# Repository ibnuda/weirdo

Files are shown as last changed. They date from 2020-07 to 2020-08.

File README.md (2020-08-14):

# Weirdo

It's a split keyboard that uses 1 Promicro (or its clone) and RJ45.

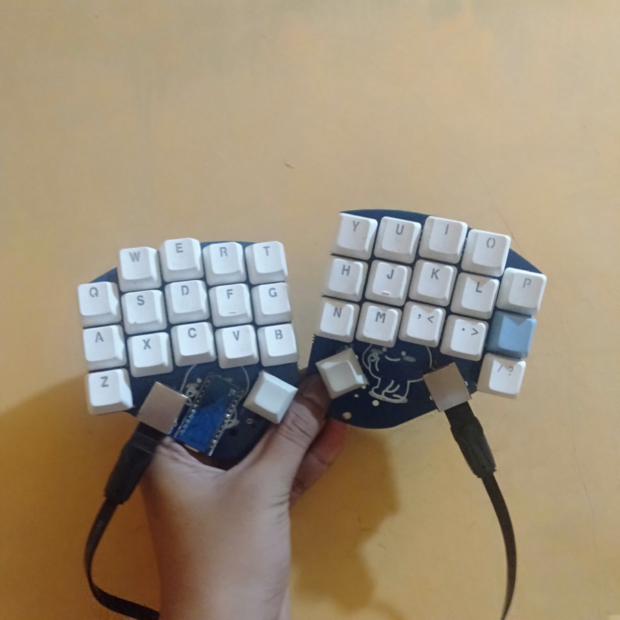
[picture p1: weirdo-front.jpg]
Front


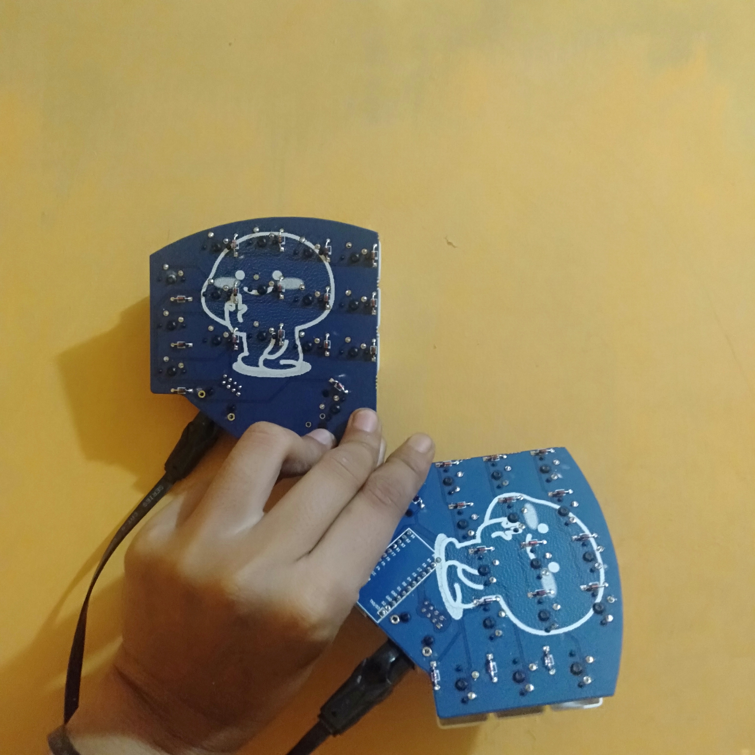
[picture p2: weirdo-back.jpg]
Back


## Why?

Just because

## Does It Work?

Of course it works.

## Firmware?

It uses [QMK](https://qmk.fm) as the firmware.

## Keymaps?

Default: [default](https://github.com/ibnuda/qmk_firmware/tree/weirdo/keyboards/weirdo/keymaps/default)

[Denny Tom's Chording Engine](https://github.com/qmk/qmk_firmware/tree/master/users/dennytom/chording_engine):
[rick's combo](https://github.com/ibnuda/qmk_firmware/tree/weirdo/keyboards/weirdo/keymaps/rick-combo)

## License

GPLv3

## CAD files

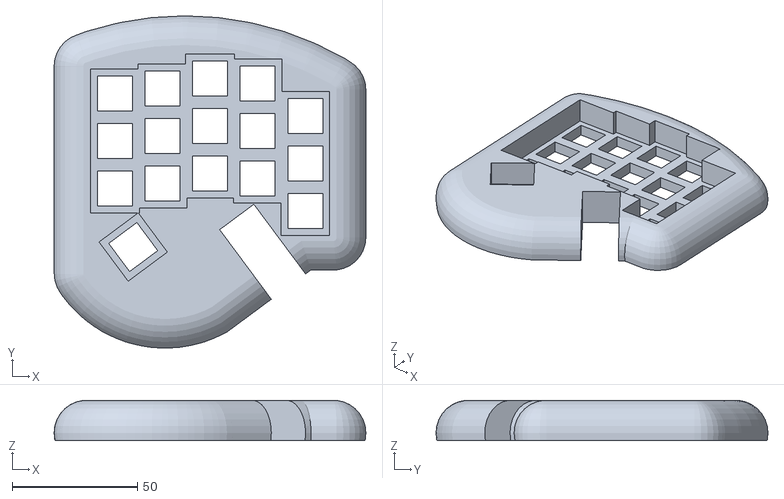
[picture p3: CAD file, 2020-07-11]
top-right-case.stl
124.5 x 132.5 x 16.0

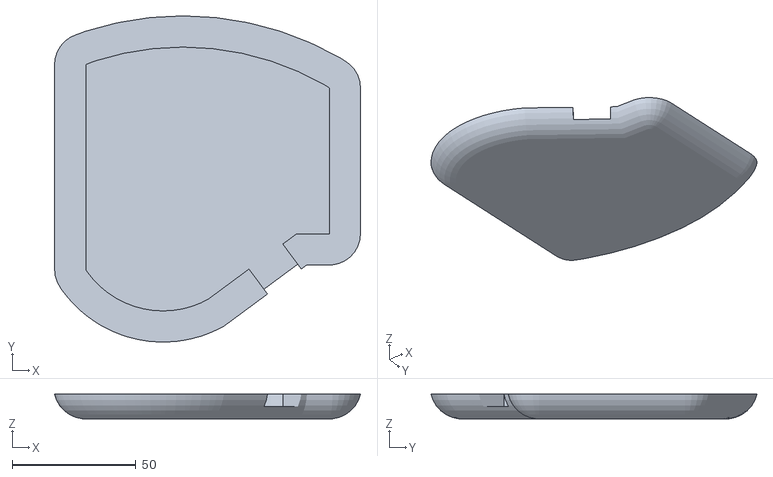
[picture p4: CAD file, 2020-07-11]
bottom-right-case.stl
123.7 x 131.8 x 9.93

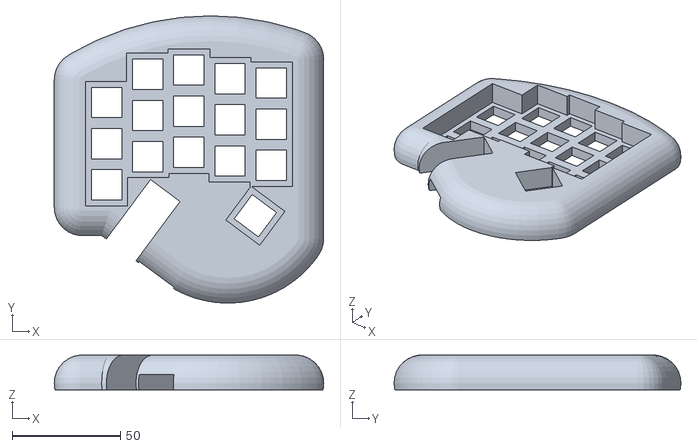
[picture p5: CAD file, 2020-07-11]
top-left-case.stl
124.5 x 132.5 x 16.0

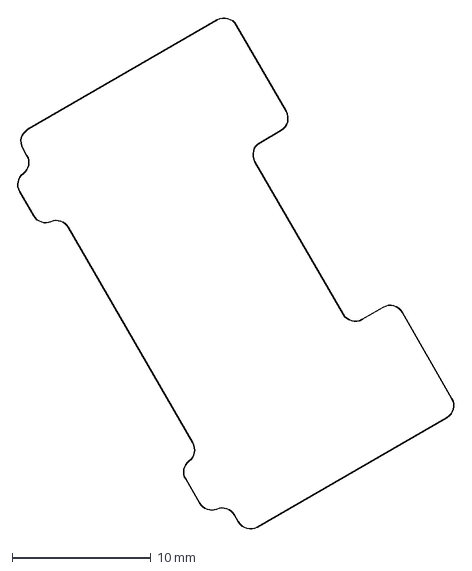
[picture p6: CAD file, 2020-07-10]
2u-cutout.dxf
31.6 x 37.0 mm

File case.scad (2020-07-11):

use_2u_left = false;
use_2u_right = false;
bottom_thickness = 5;
function cave_thickness(use_2u) = use_2u ? 7 : 5;
function plate_thickness(use_2u) = use_2u ? 3 : 5;
function lower_thickness(use_2u) = bottom_thickness +
                                   cave_thickness(use_2u);
function sandwich_thickness(use_2u) = lower_thickness(use_2u) +
                                      plate_thickness(use_2u);

module sector(radius, angles, fn = 60)
{
    r = radius / cos(180 / fn);
    step = -360 / fn;

    points = concat(
        [[ 0, 0 ]],
        [for (a = [angles[0]:step:angles[1] - 360])[r * cos(a), r * sin(a)]],
        [[r * cos(angles[1]), r * sin(angles[1])]]);

    difference()
    {
        circle(radius, $fn = fn);
        polygon(points);
    }
}

stagger = [ -44, -31, -29, -33, -35 ];

module alpha_holes(width = 14)
{
    for (j = [0:2]) {
        for (i = [0:4]) {
            translate([ (30 + i * 19), (stagger[i] - j * 19), 0 ])
            {
                square(size = [ width, width ], center = true);
            }
        }
    }
}

module
thumb_2u()
{
    translate([ 7, -6.3, 0 ])
    {
        rotate([ 0, 0, -30 ]) { import("2u-cutout.dxf"); }
    }
}

module
shape_of_promicro()
{
    translate([ -15, 0, 0 ]) square(size = [ 63, 20 ], center = true);
}

module
shape_of_rj45()
{
    translate([ -4, -39, 0 ]) square(size = [ 17, 44 ], center = false);
}

module
shape_of_pcb()
{
    union()
    {
        difference()
        {
            translate([ 78, -132, 0 ]) { sector(115, [ 70, 121 ]); }
            translate([ 78, -132, 0 ]) { sector(15, [ 69, 122 ]); }
        }
        polygon(points = [
            [ 18.81, -33.5 ],
            [ 18.81, -92.5 ],
            [ 32, -92.5 ],
            [ 67.82, -118.982 ],
            [ 117.24, -107 ],
            [ 117.24, -24 ]
        ]);
        translate([ 86, -86, 0 ]) { sector(37.68, [ 241, 326.1 ]); }
    }
}

module base_case(use_2u)
{
    difference()
    {
        minkowski()
        {
            translate([ 0, 0, 13 ]) sphere(r = 13);
            linear_extrude(height = 0.1) { shape_of_pcb(); }
        }
        translate([ 0, 0, bottom_thickness ])
            linear_extrude(height = cave_thickness(use_2u)) shape_of_pcb();
        translate([ 0, 0, lower_thickness(use_2u) ])
            linear_extrude(height = plate_thickness(use_2u)) alpha_holes(14);
        translate([ 0, 0, sandwich_thickness(use_2u) ]) linear_extrude(height = 18)
            alpha_holes(19.5);
        if (use_2u) {
            translate([ 93, -104, lower_thickness(use_2u) ]) rotate([ 0, 0, 323.4 ])
                linear_extrude(height = plate_thickness(use_2u)) thumb_2u();
            translate([ 93, -104, sandwich_thickness(use_2u) ]) rotate([ 0, 0, 323.4 ])
                linear_extrude(height = 18)
                    square(size = [ 19.5, 39 ], center = true);
        } else {
            translate([ 98.7, -96.3, lower_thickness(use_2u) ]) rotate([ 0, 0, 233.4 ])
                linear_extrude(height = plate_thickness(use_2u))
                    square(size = [ 14, 14 ], center = true);
            translate([ 98.7, -96.3, sandwich_thickness(use_2u) ])
                rotate([ 0, 0, 233.4 ]) linear_extrude(height = 18)
                    square(size = [ 19.5, 19.5 ], center = true);
        }
    }
}

module
left_case()
{
    difference()
    {
        base_case(use_2u_left);
        translate([ 72, -98, bottom_thickness ]) rotate([ 0, 0, 53.4 ])
            linear_extrude(height = 12) shape_of_promicro();
        translate([ 50.5, -86, bottom_thickness ]) rotate([ 0, 0, 323.4 ])
            linear_extrude(height = 22) shape_of_rj45();
    }
}

module
bottom_left_case()
{
    difference()
    {
        left_case();
        translate([ 0, -400, lower_thickness(use_2u_left) ])
            cube(size = [ 400, 400, 30 ], center = false);
    }
}

module
top_left_case()
{
    difference()
    {
        left_case();
        translate([ 0, -400, (0 - 30 + lower_thickness(use_2u_left)) ])
            cube(size = [ 400, 400, 30 ], center = false);
    }
}

module
right_case()
{
    difference()
    {
        translate([ 235, 0, 0 ]) mirror(v = [ 1, 0, 0 ])
            base_case(use_2u_right);
        translate([ 177, -91, bottom_thickness ]) rotate([ 0, 0, 36.6 ])
            linear_extrude(height = 22) shape_of_rj45();
    }
}

module
bottom_right_case()
{
    difference()
    {
        right_case();
        translate([ 77, -400, lower_thickness(use_2u_right) ])
            cube(size = [ 400, 400, 30 ], center = false);
    }
}

module
top_right_case()
{
    difference()
    {
        right_case();
        translate([ 77, -400, (0 - 30 + lower_thickness(use_2u_right)) ])
            cube(size = [ 400, 400, 30 ], center = false);
    }
}

module base_plate(use_2u)
{
    difference()
    {
        shape_of_pcb();
        alpha_holes(14);
        if (use_2u) {
            translate([ 93, -104, 0 ]) rotate([ 0, 0, 323.4 ]) thumb_2u();

        } else {
            translate([ 98.7, -96.3, 0 ]) rotate([ 0, 0, 233.4 ])
                square(size = [ 14, 14 ], center = true);
        }
    }
}

module
left_plate()
{
    difference()
    {
        base_plate(use_2u_left);
        translate([ 72, -98, 0 ]) rotate([ 0, 0, 53.4 ]) shape_of_promicro();
        translate([ 50.5, -86, 0 ]) rotate([ 0, 0, 323.4 ]) shape_of_rj45();
    }
}

module
right_plate()
{
    difference(use_2u_right)
    {
        translate([ 235, 0, 0 ]) mirror(v = [ 1, 0, 0 ]) base_plate();
        translate([ 177, -91, 0 ]) rotate([ 0, 0, 36.6 ]) shape_of_rj45();
    }
}

module
left_pcb()
{
    union()
    {
        color("navy") linear_extrude(height = 1.6) shape_of_pcb();
        color("pink") translate([ 50.5, -86, 1.7 ]) rotate([ 0, 0, 323.4 ]) linear_extrude(height = 14) shape_of_rj45();
        color("gray") translate([ 72, -98, 0 ]) rotate([ 0, 0, 53.4 ]) linear_extrude(height = 7) shape_of_promicro();
        color("aqua") linear_extrude(height = 16) alpha_holes();
    }
}


// left_case();
// right_case();

// bottom_right_case();
// translate([ -150, 0, -lower_thickness(use_2u_right) ]) top_right_case();

// bottom_left_case();
// translate([ 150, 0, -lower_thickness(use_2u_left) ]) top_left_case();

// left_plate();
// right_plate();

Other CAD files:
bottom-left-case.stl

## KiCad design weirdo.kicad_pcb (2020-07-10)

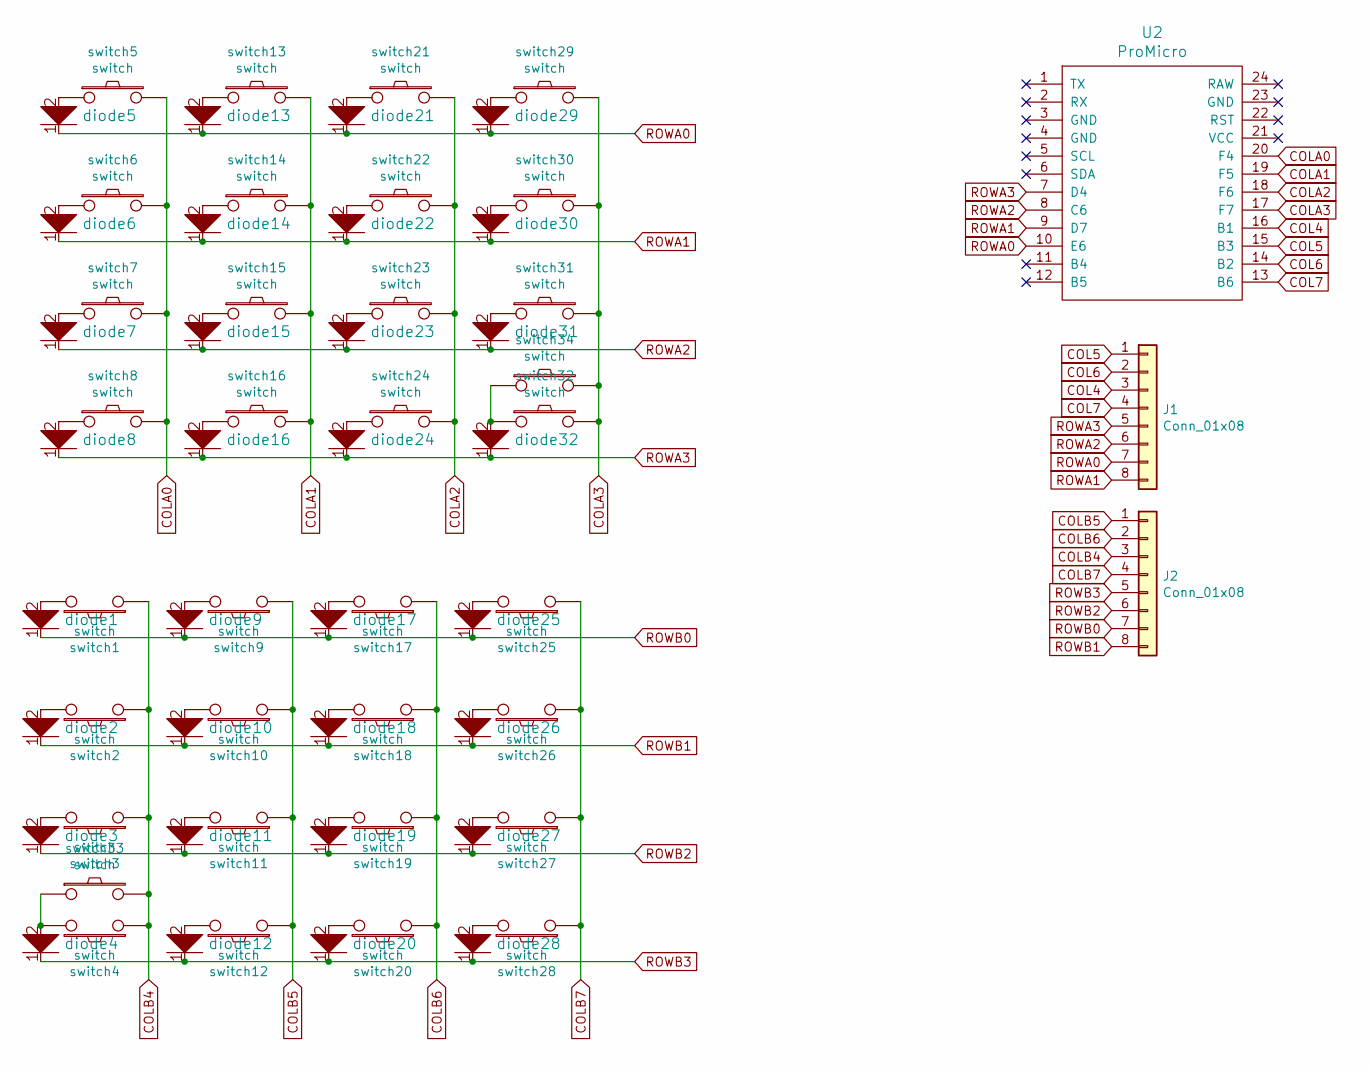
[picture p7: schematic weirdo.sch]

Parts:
J1, J2: Conn_01x08; RJ45_Ninigi_GE
U2: ProMicro; promicro
diode1, diode2, diode3, diode4, diode5, diode6, diode7, diode8, diode9, diode10, diode11, diode12, diode13, diode14, diode15, diode16, diode17, diode18, diode19, diode20, diode21, diode22, diode23, diode24, diode25, diode26, diode27, diode28, diode29, diode30, diode31, diode32: diode
switch1, switch2, switch3, switch5, switch6, switch7, switch8, switch9, switch10, switch11, switch12, switch13, switch14, switch15, switch16, switch17, switch18, switch19, switch20, switch21, switch22, switch23, switch24, switch25, switch26, switch27, switch28, switch29, switch30, switch31, switch33, switch34: switch; 1u-single
switch4, switch32: switch; 2u-single

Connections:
COL4: J1.3, U2.16 (B1)
COL5: J1.1, U2.15 (B3)
COL6: J1.2, U2.14 (B2)
COL7: J1.4, U2.13 (B6)
COLA0: U2.20 (F4), switch5.2, switch6.2, switch7.2, switch8.2
COLA1: U2.19 (F5), switch13.2, switch14.2, switch15.2, switch16.2
COLA2: U2.18 (F6), switch21.2, switch22.2, switch23.2, switch24.2
COLA3: U2.17 (F7), switch29.2, switch30.2, switch31.2, switch32.2, switch34.2
COLB4: J2.3, switch1.1, switch2.1, switch3.1, switch4.1, switch33.2
COLB5: J2.1, switch9.1, switch10.1, switch11.1, switch12.1
COLB6: J2.2, switch17.1, switch18.1, switch19.1, switch20.1
COLB7: J2.4, switch25.1, switch26.1, switch27.1, switch28.1
unnamed: diode1.2, switch1.2
unnamed: diode2.2, switch2.2
unnamed: diode3.2, switch3.2
unnamed: diode4.2, switch4.2, switch33.1
unnamed: diode5.2, switch5.1
unnamed: diode6.2, switch6.1
unnamed: diode7.2, switch7.1
unnamed: diode8.2, switch8.1
unnamed: diode9.2, switch9.2
unnamed: diode10.2, switch10.2
unnamed: diode11.2, switch11.2
unnamed: diode12.2, switch12.2
unnamed: diode13.2, switch13.1
unnamed: diode14.2, switch14.1
unnamed: diode15.2, switch15.1
unnamed: diode16.2, switch16.1
unnamed: diode17.2, switch17.2
unnamed: diode18.2, switch18.2
unnamed: diode19.2, switch19.2
unnamed: diode20.2, switch20.2
unnamed: diode21.2, switch21.1
unnamed: diode22.2, switch22.1
unnamed: diode23.2, switch23.1
unnamed: diode24.2, switch24.1
unnamed: diode25.2, switch25.2
unnamed: diode26.2, switch26.2
unnamed: diode27.2, switch27.2
unnamed: diode28.2, switch28.2
unnamed: diode29.2, switch29.1
unnamed: diode30.2, switch30.1
unnamed: diode31.2, switch31.1
unnamed: diode32.2, switch32.1, switch34.1
ROWA0: J1.7, U2.10 (E6), diode5.1, diode13.1, diode21.1, diode29.1
ROWA1: J1.8, U2.9 (D7), diode6.1, diode14.1, diode22.1, diode30.1
ROWA2: J1.6, U2.8 (C6), diode7.1, diode15.1, diode23.1, diode31.1
ROWA3: J1.5, U2.7 (D4), diode8.1, diode16.1, diode24.1, diode32.1
ROWB0: J2.7, diode1.1, diode9.1, diode17.1, diode25.1
ROWB1: J2.8, diode2.1, diode10.1, diode18.1, diode26.1
ROWB2: J2.6, diode3.1, diode11.1, diode19.1, diode27.1
ROWB3: J2.5, diode4.1, diode12.1, diode20.1, diode28.1

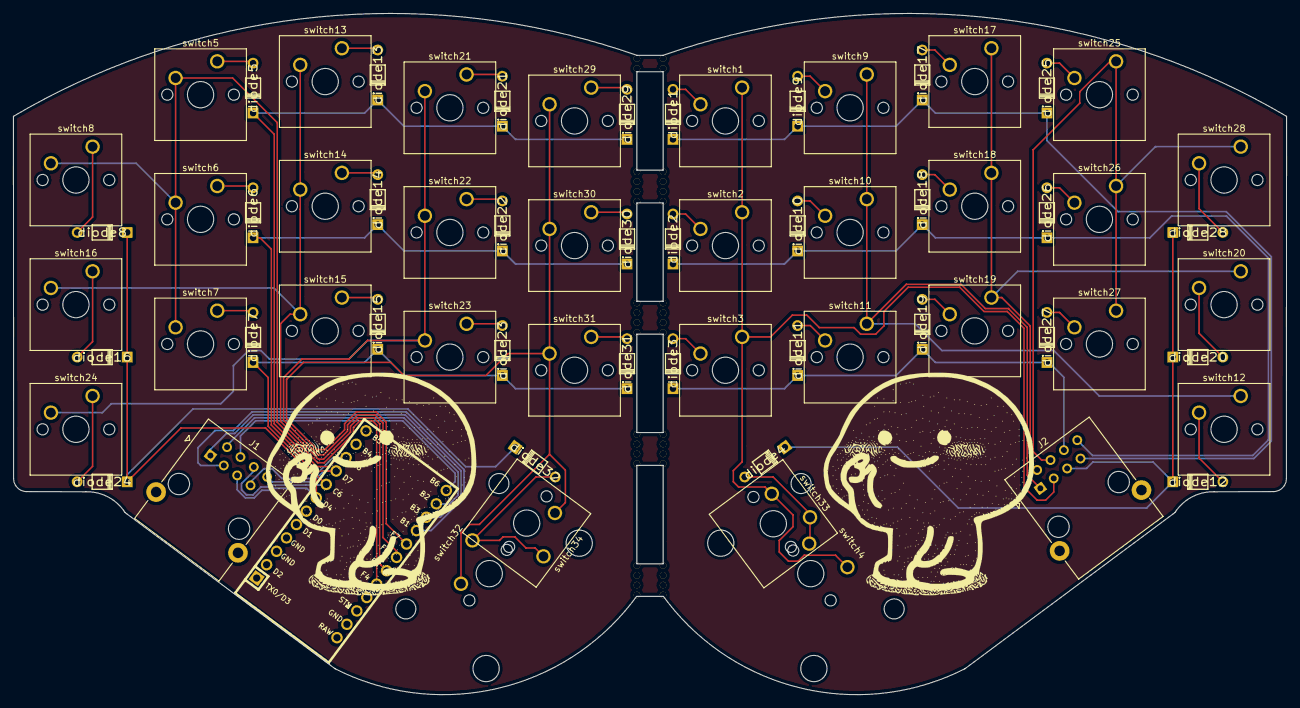
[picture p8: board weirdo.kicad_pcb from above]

Board: 2 copper layers, 194.0 x 103.8 mm, 87 parts (1 on the bottom side), 52 nets.

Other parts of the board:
Ref**: Val**; holes_two
Ref**#2, Ref**#3, Ref**#4, Ref**#5, Ref**#6, Ref**#7, Ref**#8, Ref**#9, Ref**#10, Ref**#11, Ref**#12, Ref**#13, Ref**#14, Ref**#15, Ref**#16, Ref**#17, Ref**#18: Val**; holes_two
